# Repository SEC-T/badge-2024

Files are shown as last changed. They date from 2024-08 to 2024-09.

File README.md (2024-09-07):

# SEC-T 0x10sion Music Synthesizer Badge kit
photo of SEC-T 0x10sion Music Synthesizer Badge

The SEC-T 0x10sion Music Synthesizer Badge is a kit that attendees of SEC-T 0x10sion 2024 must solder together.
It is an Arduino-compatible music synthesizer kit with:
* a touch keyboard
* built-in speaker/amp
* audio output jack (for high-quality audio)
* 5 programmable RGB LEDs

It is designed to be perfect for total beginners to learn to solder and complete successfully.

The SEC-T Synth Badge comes with a pre-programmed music synthesizer that makes way cool sounds and music and noise.
Once soldering is completed, the SEC-T Synth Badge is a really nice, portable, performing musical instrument!

The SEC-T Synth Badge kit is based on the ArduTouch music synthesizer kit by Mitch Altman / Cornfield Electronics,
which is fully Open Hardware, with a CC BY-SA 4.0 license.

The SEC-T Synth Badge makes use of a modified ArduTouch library, which is available for
programming in more super nice synthesizer features, and for making your own synthesizers.
The library comes with examples (with more to come) that serve as a nice tutorial
on how to create your own SEC-T Synth Badge synthesizers (which are Arduino sketches).

The SEC-T Synth Badge is really just an Arduino Uno clone
with the features listed above, a couple of extra buttons, and a four of pots (for playing music and controlling the sounds).
The ArduTouch Arduino Library is where the real magic comes from!

For those who want to learn more, the documentation teaches the basics of Digital Signal Processing for audio generation.

The SEC-T Synth Badge kit is fully Open Hardware, with a CC BY-SA 4.0 license.

Open Hardware logo

---
## Assembly Instructions (with re-programming how-to)

_Click on the image below to open a PDF file with detailed instructions on how to assemble your SEC-T 0x10sion Music Synthesizer Badge (which also includes a how-to for re-programming your Synth Badge with a new Arduino sketch):_  
  
### Part 1 of 2 parts:
  
  
### Part 2 of 2 parts:
  

---
## "Quadrant" Synth Demo Videos

The Synth Badge comes pre-programmed with a synth called __Quadrant__.  
Quadrant is somewhat like a looper.  Every time you play a note it goes into the loop.  You can control the speed of the loop, and you can also make the sound warp (detune) every time through the loop.  
  
There is the default patch for Quadrant, plus 4 presets -- all 5 of these have very different sounds!  
In addition to changing the loop speed and changing the warp-factor, there are many parameters that you can play with, some of which change the sounds in subtle ways, others which change the sounds a lot.  

These demo videos give you a very small taste of the various sounds Quadrant can make. 

___NOTE__:  The demo videos use the prototype version of the SEC-T 0x10sion Music Synthesizer Badge kit._  
There are some differences between the prototype version and the badges at the event.  In particular, the two red buttons are reversed (left and right).  

__Basic Functionality of Quadrant__:  
* At power-up (or after Reset), Quadrant is in the Default Patch
* Single-Click the right red button to go up an octave
* Single-Click the left red button to go down an octave
* Double-Click the right red button and then hit one of the first four lower touch-keys to choose a preset
  * The left-most touch-key is "C" -- Scaffold
  * The next touch-key is "D" -- Farsy
  * "E" -- Teleprompt
  * "F" -- Glacial
  * "G" -- Blur
* Tap the Reset button to get the Default Patch
* The Top Pot controls the Warp-factor
* The Bottom Pot controls the speed of the loop
* Pot A controls tremelo speed
* Pot B controls tremelo depth
* Press-and-hold on the left and right red buttons will make the Red and Blue LEDs light or blink, indicating that the four Pots will now control different parameters.  
  
See the next section, "Quadrant Synth User Guide", for a complete description of all that the Quadrant Synth can do.  
  
### Default Patch (at power-up and after Reset) _-- click on the image below to play the video_
Thumb for Default Patch demo (https://www.youtube.com/watch?v=8XAPtq4mnFQ)  

### Preset "C" -- Scaffold _-- click on the image below to play the video_
Thumb for Preset "C" demo (https://www.youtube.com/watch?v=vg959F6WOIo)  

### Preset "D" -- Farsy _-- click on the image below to play the video_
Thumb for Preset "D" demo (https://www.youtube.com/watch?v=kQ33xrg7Zvw)  

### Preset "E" -- Teleprompt _-- click on the image below to play the video_
Thumb for Preset "E" demo (https://www.youtube.com/watch?v=aHm4yFb8vfQ)  

### Preset "F" -- Glacial _-- click on the image below to play the video_
Thumb for Preset "F" demo (https://www.youtube.com/watch?v=Ehx3G3c8V5c)  

### Preset "G" -- Blur _-- click on the image below to play the video_
Thumb for Preset "G" demo (https://www.youtube.com/watch?v=jeHlcZ8XYc8)  

---
## Quadrant Synth User Guide

The Synth Badge comes pre-programmed with a synth called __Quadrant__.  Quadrant is a very powerful performing musical instrument.  
_Click on the image below to learn how to play with it:_  
  

---
## Re-programming the Synth Badge

The Synth Badge can be re-programmed using the free Arduino software (on Windows, Linux, and MacOS).  
The end pages of the [Synth Assembly Instructions](https://github.com/user-attachments/files/16896082/SEC-T_0x10sion_badge_assembly_part_2of2.pdf) explain how to do this.  
To re-program your Synth Badge you will need to use a USB-Serial TTL adapter.  
  
The Synth Badge comes pre-programmed with the __Quadrant__ synth.  
  
There are 8 other synths that were developed for the open hardware_ArduTouch_ project (which the Synth Badge is based on), all of which will work on the SEC-T Synth Badge.  But you should be aware of the following:  
* The Synth Badge has 5 programmable RGB LEDs that the _ArduTouch_ boards do not have.  
* The __Quadrant__ synth sketch (from the Synth Badge's Github) has code for controlling the RGB LEDs, but the _ArduTouch synth sketches do not -- though this functionality can be added by you or others.  
* The Synth Badge does not have touch-keys for "A, A#, or B).
  
All of the documentation for [ArduTouch](https://cornfieldelectronics.com/cfe/projects.php#ardutouch), including the synth sketches, is available on the Cornfield Electronics website:  
https://cornfieldelectronics.com/cfe/projects.php#ardutouch  
  
Here is a list of ArduTouch synths that you can program into your Synth Badge:
* __Thick__: 4-voice sawtooth synth
* __Arpology__: Arpegiating synth
* __Beatitude__: drum sequencer with bass synth
* __Dronetic__: drone-making synth
* __Hocus__: Hammond organ (with Leslie) emulator synth
* __Mantra__: Indian-like percusion/bass/drone/melody synth
* __Xoid__: Digital-noise synth
* __ZapShot__: 8-bit video-game-sound synth

---
## A Note on the (Horrible) User Interface for the Quadrant Synth

As noted in the [Quadrant Synth User Guide](https://github.com/user-attachments/files/16901048/Quadrant_Synth_User_Guide.pdf) (see the "Quadrant Synth User Guide", above), the User Interface is really annoying.  

The following is quoted from the Quadrant Synth User Guide:  
  
&nbsp;&nbsp;&nbsp;&nbsp;&nbsp;&nbsp;_You will be annoyed at the User Interface for this synth.  Sorry about that.  The reason that it is so annoying  
&nbsp;&nbsp;&nbsp;&nbsp;&nbsp;&nbsp;is that there are so few Input/Output pins available on the microcontroller.  There were only enough I/O pins  
&nbsp;&nbsp;&nbsp;&nbsp;&nbsp;&nbsp;for 2 LED indicators, 2 Buttons, and 4 Pots._  
  
&nbsp;&nbsp;&nbsp;&nbsp;&nbsp;&nbsp;_I had to come up with a way to control all of the functionality of the Quadrant synth with only the above inputs  
&nbsp;&nbsp;&nbsp;&nbsp;&nbsp;&nbsp;and outputs.  The result is not ideal.  Yet, with some practice, you will find that your Quadrant synth is quite  
&nbsp;&nbsp;&nbsp;&nbsp;&nbsp;&nbsp;usable as a really nice performing musical instrument._  
  
&nbsp;&nbsp;&nbsp;&nbsp;&nbsp;&nbsp;_FYI:  I chose this microcontroller to be the same as the one used in an Arduino Uno:  ATmega328.  This was so  
&nbsp;&nbsp;&nbsp;&nbsp;&nbsp;&nbsp;that the project would be easy to use for beginners, easy to learn for beginners, easy to hack, and also as  
&nbsp;&nbsp;&nbsp;&nbsp;&nbsp;&nbsp;inexpensive as possible._  

---
## Schematic Diagram

_Click on the thumbnail below to to see the PDF file:_  


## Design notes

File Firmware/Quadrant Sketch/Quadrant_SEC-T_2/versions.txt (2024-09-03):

Versions:

   1.74sect added control for Neopixel LEDs, changed for 4 pots and only 9 touch-keys
   1.74c no need to explicitly clear flags.RSTMUTE
   1.74b add host/host.ini with pot labels
         add Stock.atp
   1.74a bck.bat copies host subdirectory and contents
         add host/preset .atp files for all presets
   1.73  use embedded U/I frames 
         syncs with library 1.16
   1.72  bugfix: upper bound condition in LED iteration corrected to "< NUMLEDs" from "<= NumLEDs"
         [31722] _STNDLONE_ lib 1.15 Build 1.6.6
   1.71  newOsc() returns NULL (instead of new Osc())
   1.70  nix BUILD_166 conditional compilation sections
   1.69  add FRAME21 pots to control lead 1 detune and transpose
         [31742] _STNDLONE_ BUILD_166
   1.68  edit presets/macros to use byte values <= 128 when setting LFO depths 
         syncs with library 1.13
         [31684] _STNDLONE_ BUILD_166
   1.67  === FIRST PUBLISHED VERSION ===

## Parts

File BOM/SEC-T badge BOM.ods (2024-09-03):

 | SEC-T Synth badges
Qty | Designator | Part Description | ordering url
1 | small bag | 5cm*7cm reclosable bags, 2 mil | https://www.amazon.se/-/en/plastic-closure-resealable-pressure-sealing/dp/B09QJYYYVR
4 | C1, C2, C3, C4 | 0.1uF, 50V, ceramic, 0.1" spacing leads | https://www.mouser.de/ProductDetail/80-C320C104K1R5TA
2 | C5, C6 | 100uF, 16V or higher, electrolytic, radial, 0.1" spacing leads | https://www.mouser.de/ProductDetail/710-860010473007
2 | C7, C8 | 1uF, 16V or higher, electrolytic, radial, 0.1" spacing leads | https://www.mouser.de/ProductDetail/232-450PK1MEFC6.3X11
1 | LED1 | Blue LED, 5mm | https://www.mouser.de/ProductDetail/710-151051BS04000
1 | LED2 | Red LED, 5mm | https://www.mouser.de/ProductDetail/442-BLBJE5V4VAT
1 | LED3 | Green LED, 5mm | https://www.mouser.de/ProductDetail/710-151051VS04000
1 | R1 | 10K, 1/4W, 5% | https://www.mouser.de/ProductDetail/708-CF18JT10K0
3 | R2, R3, R4 | 1K, 1/4W, 5% | https://www.mouser.de/ProductDetail/603-CFR-25JT-52-1K
2 | R5, R6 | 270, 1/4W, 5% | https://www.mouser.de/ProductDetail/603-CFR-25JT-52-270R
2 | R7, R8 | 4.7K, 1/4W, 5% | https://www.mouser.de/ProductDetail/603-CFR-25JR-524K7
1 | X1 | 16.0MHz ceramic resonator | https://www.mouser.de/ProductDetail/81-CSTLS16M0X53-B0
1 | medium bag | 12cm*8cm reclosable bags, 6.3 mil | https://www.amazon.se/-/en/huruirui-Resealable-Multiple-Assortment-Packaging/dp/B0BNC67X1M
1 | B1 | 3xAA battery holder w/ leads, switch, cover | https://www.mouser.de/ProductDetail/12BH331P-GR
1 | J1 | 1x6, right-angle (FTDI) | https://www.mouser.de/ProductDetail/649-1012937990604BLF
1 | J3 | headphone, stereo, 3.5mm, switched | https://www.mouser.de/ProductDetail/490-SJ1-3525NG-GR
1 | R9 | 10K trim pot (screwdriver adjust - Volume) | https://www.mouser.de/ProductDetail/652-3306F-1-103
4 | R10, R11, R12, R13 | 10K pot | https://www.mouser.de/ProductDetail/858-P120PKY25BR10K
1 | S1 | SPST tact switch, 4-pin, Black button (Reset) | https://www.mouser.de/ProductDetail/179-TS026660BK260LCR
2 | S2, S3 | SPST tact switch, 4-pin, Red button | https://www.mouser.de/ProductDetail/113-DTS65RV
1 | S4 | SPST slide switch | https://www.mouser.de/ProductDetail/611-OS102011MS2QS1
1 | U1 | ATmega328P-PU | https://www.mouser.de/ProductDetail/556-ATMEGA328P-PU
1 | U1 socket | 28-pin DIP socket | https://www.mouser.de/ProductDetail/571-1-2199298-9
1 | U2 | LM386N | https://www.mouser.de/ProductDetail/926-LM386N-1-NOPB
1 | U2 socket | 8-pin DIP socket | https://www.mouser.de/ProductDetail/571-1-2199298-2
1 | large bag | 15cm*20cm reclosable bags, 2 mil | https://www.amazon.se/-/en/gp/product/B0C9JKWSXJ
4 | LED4, LED5, LED6, LED7, LED8 | WS2812 RGB LED, 5mm | https://www.digikey.de/de/products/detail/sparkfun-electronics/COM-12986/5673799
1 | PCB | Multi-Circuit-Boards.eu | https://multi-circuit-boards.eu
1 | SPKR1 | speaker, 3W, 4 Ohm, 40mm diamater | https://www.electrokit.com/en/miniatyrhogtalare-8ohm-0.5w-20mm
1 | small bag (and its contents)
1 | med bag (and its contents)
1 | Card
1 | Lanyard | ~70cm long, with "J"-hook on each end

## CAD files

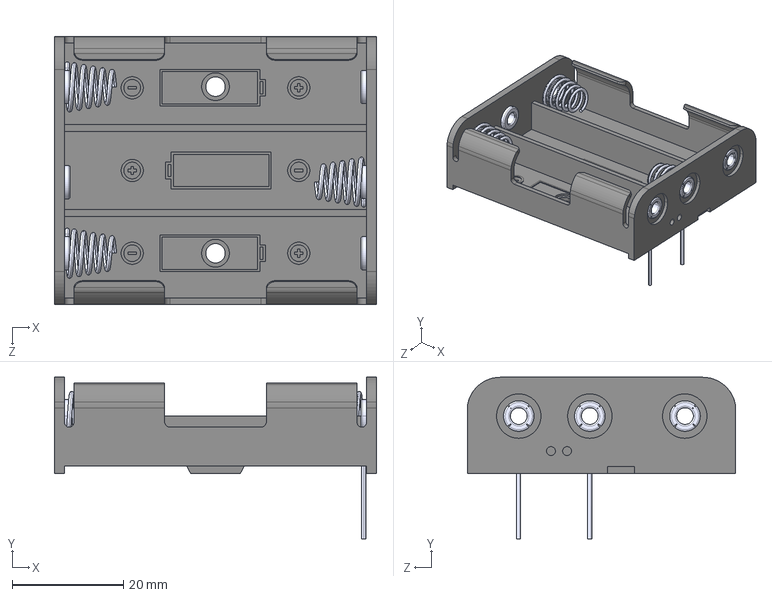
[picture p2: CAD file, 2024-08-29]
KiCad/3D_Models/12BH331P-GR--3DModel/12BH331P-GR--3DModel.STEP
58.0 x 29.1 x 48.3 mm

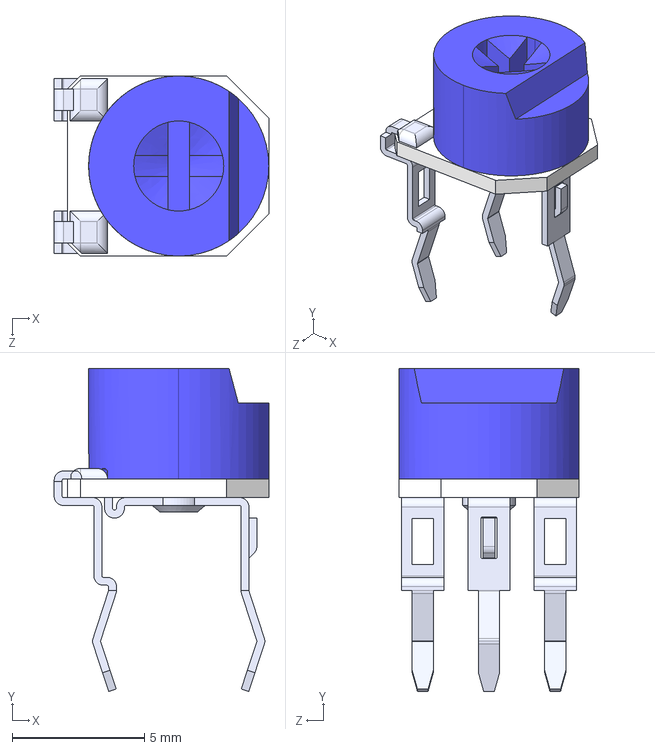
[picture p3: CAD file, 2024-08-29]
KiCad/3D_Models/3306F-1-103--3DModel/3306F-1-103.STEP
8.10 x 12.2 x 6.81 mm

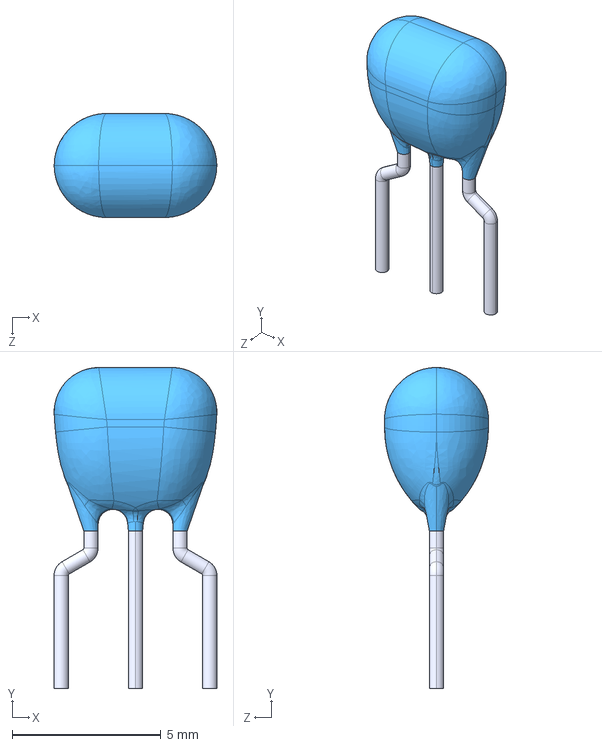
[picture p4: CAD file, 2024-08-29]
KiCad/3D_Models/CSTLS16M0X53-B0--3DModel/CSTLS16M0X53-B0.STEP
5.48 x 10.8 x 3.50 mm

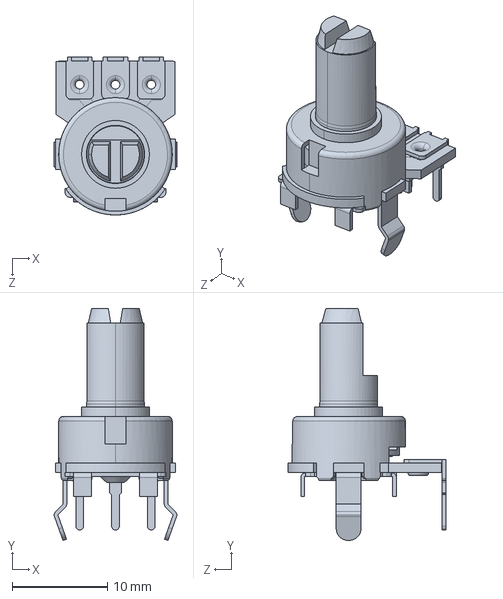
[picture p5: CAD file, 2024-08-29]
KiCad/3D_Models/P120PK-Y25BR10K--3DModel/P120PK-Y25BR10K.stp
12.8 x 24.3 x 16.6 mm

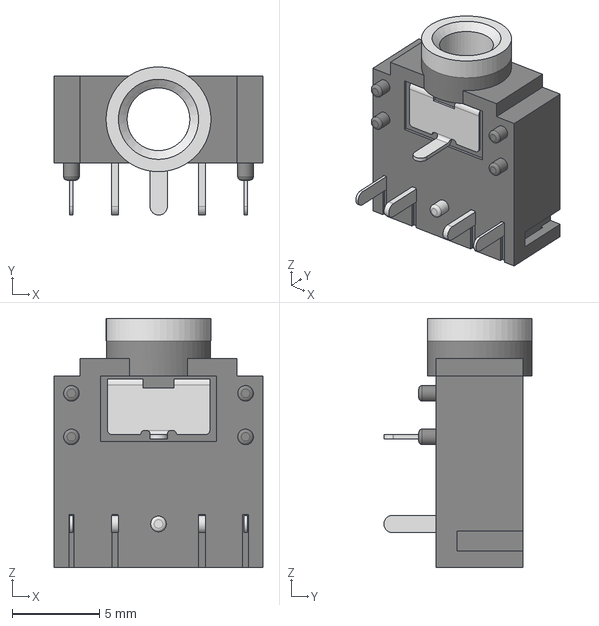
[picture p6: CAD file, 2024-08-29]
KiCad/3D_Models/SJ1-3525N--3DModel/SJ1-3525N.stp
12.0 x 8.51 x 14.3 mm

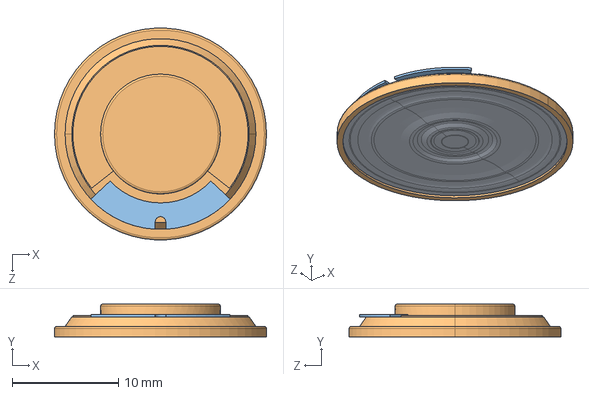
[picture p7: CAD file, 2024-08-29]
KiCad/3D_Models/speaker--3DModel/CUI_DEVICES_CDM-20008.step
20.0 x 3.10 x 20.0 mm

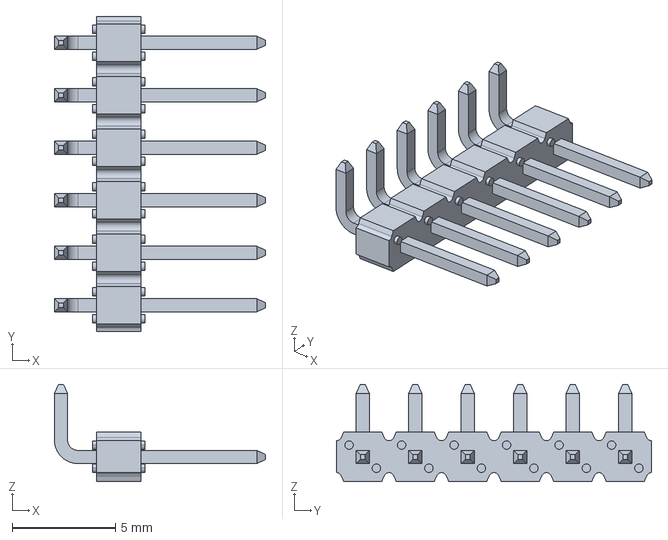
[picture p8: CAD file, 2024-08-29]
KiCad/3D_Models/10129379-906002BLF--3DModel/10129379-906002BLF--3DModel-STEP-533217.STEP
10.2 x 15.2 x 4.70 mm

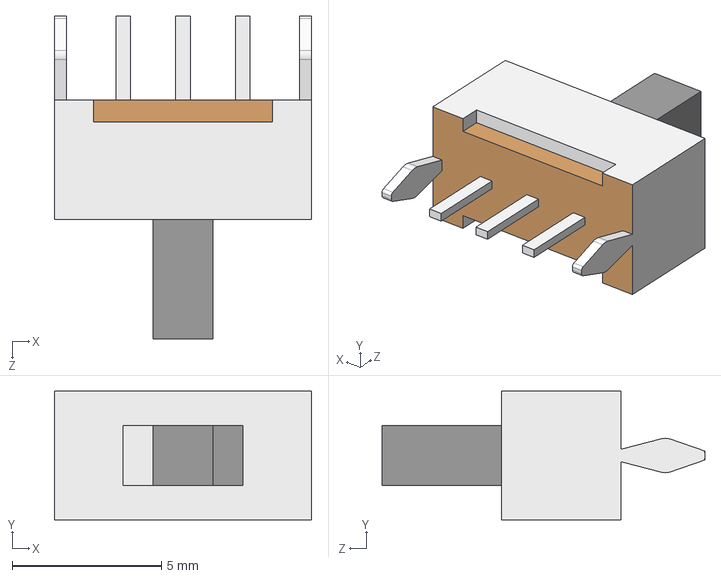
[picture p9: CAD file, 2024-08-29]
KiCad/3D_Models/OS102011MS2QS1--3DModel/OS102011MS2QS1.stp
8.60 x 4.30 x 10.8 mm

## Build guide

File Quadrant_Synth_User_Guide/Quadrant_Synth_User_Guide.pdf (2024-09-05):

## Quadrant

A partly echoing, partly arpeggiating, possibly warped synth for the ArduTouch / SEC‐T 0x10sion Music Synthesizer Bagde.

How to use:

-------- Presets --------

There are lots of way cool presets!

A list of all Presets can be seen on page 8 of this document.

Load preset sounds by Double-Tapping the Right Button and then pressing any bottom-row touch-key.

Note: A list of all types of Button presses this synth uses, including “Double-Tapping” can be seen on page 8 of this document.

Once you choose a preset, play notes on the keyboard and twiddle the knobs while playing and see what beautiful and also warped sounds and music you can create!

If you want to have more control over lots of cool and warped sounds available with the Quadrant synth, the following pages will explain how.

-------- A Note on the User Interface --------

You will be annoyed at the User Interface for this synth. Sorry about that. The reason that it is so annoying is that there are so few Input/Output pins available on the microcontroller. There were only enough I/O pins for 2 LED indicators, 2 Buttons, and 4 Pots.

I had to come up with a way to control all of the functionality of the Quadrant synth with only the above inputs and outputs. The result is not ideal. Yet, with some practice, you will find that your Quadrant synth is quite usable as a really nice performing musical instrument.

FYI: I chose this microcontroller to be the same as the one used in an Arduino Uno: ATmega328. This was so that the project would be easy to use for beginners, easy to learn for beginners, easy to hack, and also as inexpensive as possible.

==== Audio/Control Flow Diagram for the Quadrant Synth ====

| Tropes | --------.
v
.-----------> | | Echotron | |
| | v | v | v
| Lead 0 | ---> | | Mixer | | <--- | Lead 1 |
| v | v

[ Audio out ]

Lead 0 is duplicated in the opposite audio channel by Lead 1 (which may be transposed and/or detuned from Lead 0). The note information for Lead 0 is also fed into the Echotron. At the same time, a "trope" (an arpeggiation pattern) can be applied to the echoed note. The output from the Echotron is internally panned in stereo and then fed into a mixer along with the audio output from Lead 0 and Lead 1.

==== The Echotron Unit ====

The Echotron is a stereo synthesizer in its own right.

At the heart of the Echotron is a carousel of "slots", each of which holds an instance of an echoing note:

| | | | <--- WARP FACTOR
| | Note Carousel | |
| | | | <--- DELAY TIME
| Slot 0 < Slot 1 < Slot 2 < Slot 3 |
| | | | <--- FEEDBACK
v
note out

The carousel is constantly "revolving", outputting the note held in the current slot (the left-most slot in the above diagram), then shifting the slots.

The speed at which the carousel revolves is controlled by the DELAY TIME.

Each time a note echoes its volume will decrease by an amount controlled by the FEEDBACK setting. If FEEDBACK is set to its highest value (255) then the note will echo forever, or until all the slots in the carousel have been used up, and a new incoming note "overwrites" it.

Each time a note echoes its pitch can be raised or lowered by the current WARP FACTOR.

The number of slots in the carousel is configurable and can be set interactively via the Parameter Menu (see below) to between 1 and 4.

----- Tropes ------

The above description of the note carousel is a simplification. In fact, each slot can contain not just a note, but also a pointer to a "trope" (an arpeggiation pattern) in ROM. Each time the carousel revolves it will play the next note in the arpeggiation pattern for that slot.

----- Note HOLD ------

You can instruct the Echotron to HOLD the next note played (see the Parameter Menu below). When a note is on HOLD it will not decrease in volume as it echoes, and it will not be overwritten by incoming notes when the carousel is full. This is a very useful feature for setting up a constant bass pulse and jamming over it. Better yet, if a trope is active when you hold the note, then you can set up a whole bass line or texture to be played over. And you can hold more than one note :)

----- SAMPLE & HOLD ------

You can globally freeze whatever sound loop the Echotron is producing by enabling SAMPLE & HOLD (toggled via the Parameter Menu, see below). Then you can jam over it freely.

----- ISO-TEMPO -------

This feature allows the Echotron to maintain a constant tempo, regardless of the number of notes in the carousel. So if there are 4 notes currently echoing in the carousel and ISO-TEMPO is on, then the delay time will be 1/4 of what it would be if there were only 1 note in the carousel. The "Telepromt" and "Frara Jaqua" presets use ISO-TEMPO. You can toggle ISO_TEMPO via the Parameter Menu (see below). (NOTE: The "Frara Jaqua" preset is not available on the Synth Badge.)

----- ENVELOPE ------

A master envelope dynamically controls the amplitude of the notes produced by the Echotron. This envelope is a traditional ADSR (Attack/Decay/Sustain/Release) but with a twist: a Sustain Time parameter is added. When the envelope for an echoing note reaches the sustain stage it will automatically release after the
amount of time specified by the sustain time parameter. The various stages of the master envelope can be controlled via the Pots (see below).

----- PULSE WIDTH ------

The notes produced by the Echotron use square wave oscillators. The PULSE WIDTH of these oscillators can be modified via a Pot (see below). The pulse width controls the ratio between the positive and negative edges of the square wave and can radically alter the timbre of the tones.

----- AUTO-WAH ------

The Echotron has a pair of internal autowahs (oscillating low-pass filters) which are applied to the note output before it is panned. Three parameters control the autowah behaviour: CUTOFF frequency, oscillation FREQ, and oscillation DEPTH. All of these can be modified via the Pots (see below).

----- PAN CONTROL ------

A PAN control dynamically rotates the note output in the stereo field. The DEPTH and FREQ of the panning can be controlled via the Pots (see below).

==== Overview Diagram of the Echotron ====

Now that we have covered each component, here is an overall view:

[HOLD] | notes | in | [SAMPLE & HOLD]
\ | |
\ | v
----------------- | < WARP >
Trope in ---> | | Note Carousel | | < DELAY > | [ISO-TEMPO]
----------------- | < FEEDBACK >
------------- | | | < # SLOTS >
| ENVELOPE | | notes | out
| <Attack> | | |
| <Decay> | | | v
| <Sustain> | | -----------------------------
| <SusTime> | | | | AutoWahs | |
| <Release> | | | <CUTOFF> <FREQ> <DEPTH> |
v | v
-----------------------------| <---- Pan Control ----> |
| | <FREQ> <DEPTH> | |
| | audio out | |
v | v

==== PLAYING THE KEYBOARD ====

The Quadrant keyboard is a mono-touch instrument: you can play one note at a time.

To raise the keyboard by an octave, Tap the Right Button once.
To lower the keyboard by an octave, Tap the Left Button once.

==== USING THE POTS TO CONTROL PARAMETERS ====

The four Pots can be used to control 18 different parameters. You can choose four parameters to control with the Left and Right Buttons.

By Pressing (not Tapping) the Left and Right Buttons you can change which four parameters the Pots control. Each time a Button is Pressed, its associated LED (Red LED for Left Button, Blue LED for Right Button) will change state (from OFF to ON to BLINKING, back to OFF etc.)

Below is a chart showing which four parameters the Pots control when the LEDs are in a given state:

Red Blue LED LED | Top POT Bottom POT Adjust A POT Adjust B POT
OFF OFF | echo echo autowah autowah WARP DELAY time FREQ DEPTH
ON OFF | echo lead/echo autowah echo FEEDBACK BALANCE CUTOFF PULSE WIDTH
BLINK OFF | panning panning lead 1 lead 1 FREQ DEPTH DETUNE** TRANSPOSE***
OFF ON | autowah autowah envelope envelope FREQ DEPTH ATTACK* DECAY*
ON ON | autowah echo envelope envelope CUTOFF PULSE WIDTH SUSTAIN* RELEASE*
BLINK ON | lead 1 lead 1 echo lead DETUNE** TRANSPOSE*** SUSTIME PORTAMENTO
OFF BLINK | envelope envelope DECAY* ----ATTACK*
ON BLINK | envelope envelope RELEASE* ----SUSTAIN*
BLINK BLINK | echo lead PORTAMENTO (weirdness) --SUSTIME

* these Pots can be configured via the Parameter Menu (see next section) to control:
1) only the LEAD voices
2) only the ECHO voices
3) both the LEAD and ECHO voices

** detunes lead1 from lead 0

*** transposes lead1 from lead0 (range is from -2 to +2 octaves)

==== USING THE PARAMETER MENU ====

You can control additional parameters by using the Parameter Menu.

To access the Parameter Menu Double-Tap the Left Button. The LEDs will now start blinking on and off in alternation: this tells you that the Parameter Menu is active. When the Parameter Menu is active the keys will no longer play notes but each key will select and modify a particular parameter as described below. Depending on the parameter, the Pot positions may also be relevant, as described below. The Parameter Menu is active until you press a key on the touch-keyboard: then the parameter associated with that key is modified, and the Parameter Menu is automatically exited (restoring the prior user interface state).

You can exit the Parameter Menu without modifying any parameters by Double-Tapping the Left Button a second time.

The list below describes what actions are taken when a key is pressed:

Key | Action
C | toggle Sample-and-Hold on/off
C# | turn Sample-and-Hold off, and unhold all held notes
D | hold next note played
D# | [ reserved ]
E | toggle lead voices on/off
F | set # of slots in carousel based on Top Pot position *
F# | toggle isoTempo or/off
G | select trope based on Bottom Pot position **
G# | [ reserved ]
A | ADSR Pots control envelopes of both lead and echo voices ***
A# | ADSR Pots control envelopes of lead voices only ***
B | ADSR Pots control envelopes of echo voices only ***

* turn Top Pot 0 to desired position (all the way left = 1,
all the way right = 4) then press F

** turn Bottom Pot to desired position (all the way left = "no trope" ) then press G

*** A, A#, and B are not available on the SEC-T Synth Badge

==== GUIDE TO QUADRANT’S PRESETS ====

The default patch is active when powered on, and after Tapping the Reset Button.

Load presets by Double-Tapping the Right Button and then pressing any bottom-row touch-key.

The presets are as follows:

Key Name | Performance Notes
C | Scaffold | lead voices off (and should stay off)
D | Farsy
E | Teleprompt lead voices off (turn them on once 2 slots are playing)
F | Glacial | play very slowly
G | Blur
A | ToneJack | *
B | FraraJaqua lead voices off (turn them on once 4 slots are playing) *

* ToneJack and FraraJaqua are not available on the SEC-T Synth Badge

Types of Button presses:

Tap: | quickly tap a Button
Press: | long‐press a Button
Double‐Tap: quickly double‐tap a Button

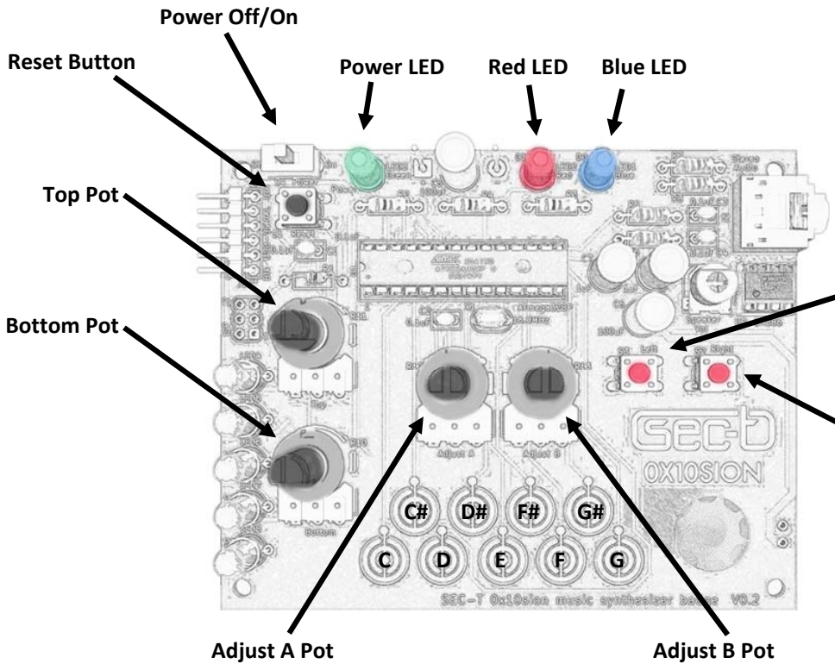
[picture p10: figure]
Power Off/On; Reset Button; Power LED; Red LED; Blue LED; Bottom Pot; Top Pot; Adjust A Pot; Adjust B Pot

Left Button

Right Button

----------------------------------------------------------------------About Quadrant's Tuning

When you start playing notes on the keyboard you will probably notice that the 'C' key plays an 'F'. And if you have a really good ear you may also notice that the interval between C# and G# is not exactly a 5th.

Why is this?

To explain the 2nd observation first, Quadrant uses Harmonic Tuning (also known as Just Temperament or "Helmholtz's scale") instead of the usual Equal Temperament (which is the system default).

Harmonic Tuning is actually more "natural" than Equal Temperament (which was created as a compromise so that keyboard instruments could play in all keys). In Harmonic Tuning the relative frequencies of all notes compared to the tonic ('C' in our case) are rational numbers:

Unison | 1/1
Minor Second 25/24
Major Second | 9/8
Minor Third | 6/5
Major Third | 5/4
Fourth | 4/3
Diminish 5th 45/32
Fifth | 3/2
Minor Sixth | 8/5
Major Sixth | 5/3
Minor Seventh 9/5
Major Seventh 15/8
Octave | 2/1

The Echotron uses quantum square wave oscillators which can only be set to frequencies which have integral wavelengths. The frequencies produced by these oscillators conform more closely to a scale in Harmonic Tuning than one in Equal Temperament.

But why does the 'C' key play an 'F'?

The short answer is that on the ArduTouch, whose audio rate is ~15.6 kHz, 'F' (in octave 1) has a period of 360 samples. 360 is a number favored by the ancients because it is divisible by a large number of integers: 1, 2, 3, 4, 5, 6, 8, 9, 10, 12, 15, 18, 20, 24, etc. It so happens that by using a tonic frequency whose period is 360, we are able to use quantum oscillators to closely approximate the Harmonic Tuning scale over several octaves. Low 'F', so to speak, is the natural tonic frequency of the ArduTouch.*

Since Quadrant's tuning is only an approximation to an 'F' Harmonic tuning, certain musical scales (such as E Major, F# Major on the ArduTouch keyboard) will sound a bit sour. C Major / D Minor work best.

* Actually, on the ArduTouch a waveform with a period of 360 samples generates a tone with a frequency of 43.578 Hz. In the equal temperament scale, 'F' in octave 1 has a frequency of 43.654 Hz.

Copyright (C) 2024, Mitch Altman
Copyright (C) 2020, Cornfield Electronics, Inc.

This work is licensed under the Creative Commons Attribution-ShareAlike 4.0
Unported License.

To view a copy of this license, visit http://creativecommons.org/licenses/by-sa/4.0/

Created by Bill Alessi & Mitch Altman.

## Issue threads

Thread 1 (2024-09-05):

Synth Badge Assembly Instructions (and re-programming guide) -- Part 1 of 2 parts

maltman23, 2024-09-05:
[SEC-T_0x10sion_badge_assembly_part_1of2_front_page.pdf](https://github.com/user-attachments/files/16895987/SEC-T_0x10sion_badge_assembly_part_1of2_front_page.pdf)

maltman23, 2024-09-05:
fixed title

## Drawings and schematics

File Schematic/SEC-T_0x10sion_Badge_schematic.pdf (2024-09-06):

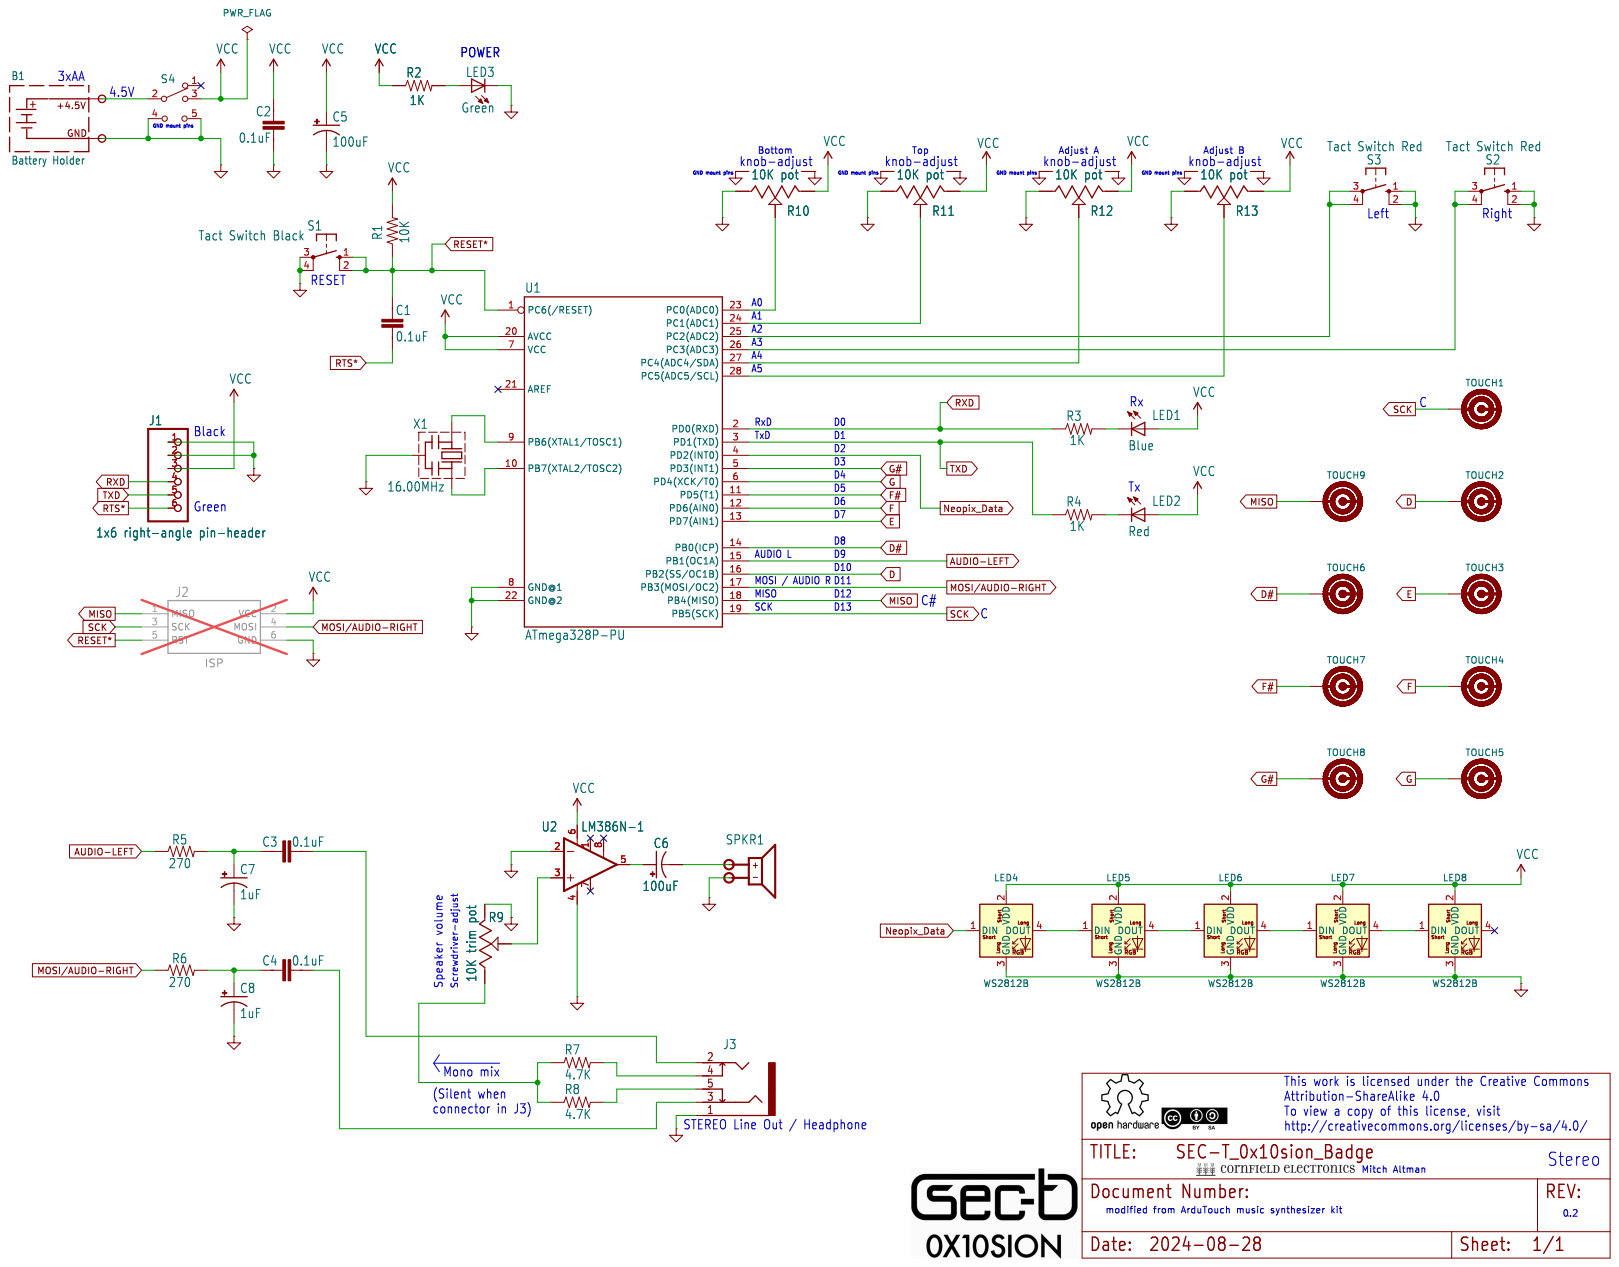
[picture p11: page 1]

AUDIO-LEFT MOSI/AUDIO-RIGHT SCK MISO

AUDIO-LEFT MOSI/AUDIO-RIGHT

This work is licensed under the Creative Commons
To view a copy of this license, visit

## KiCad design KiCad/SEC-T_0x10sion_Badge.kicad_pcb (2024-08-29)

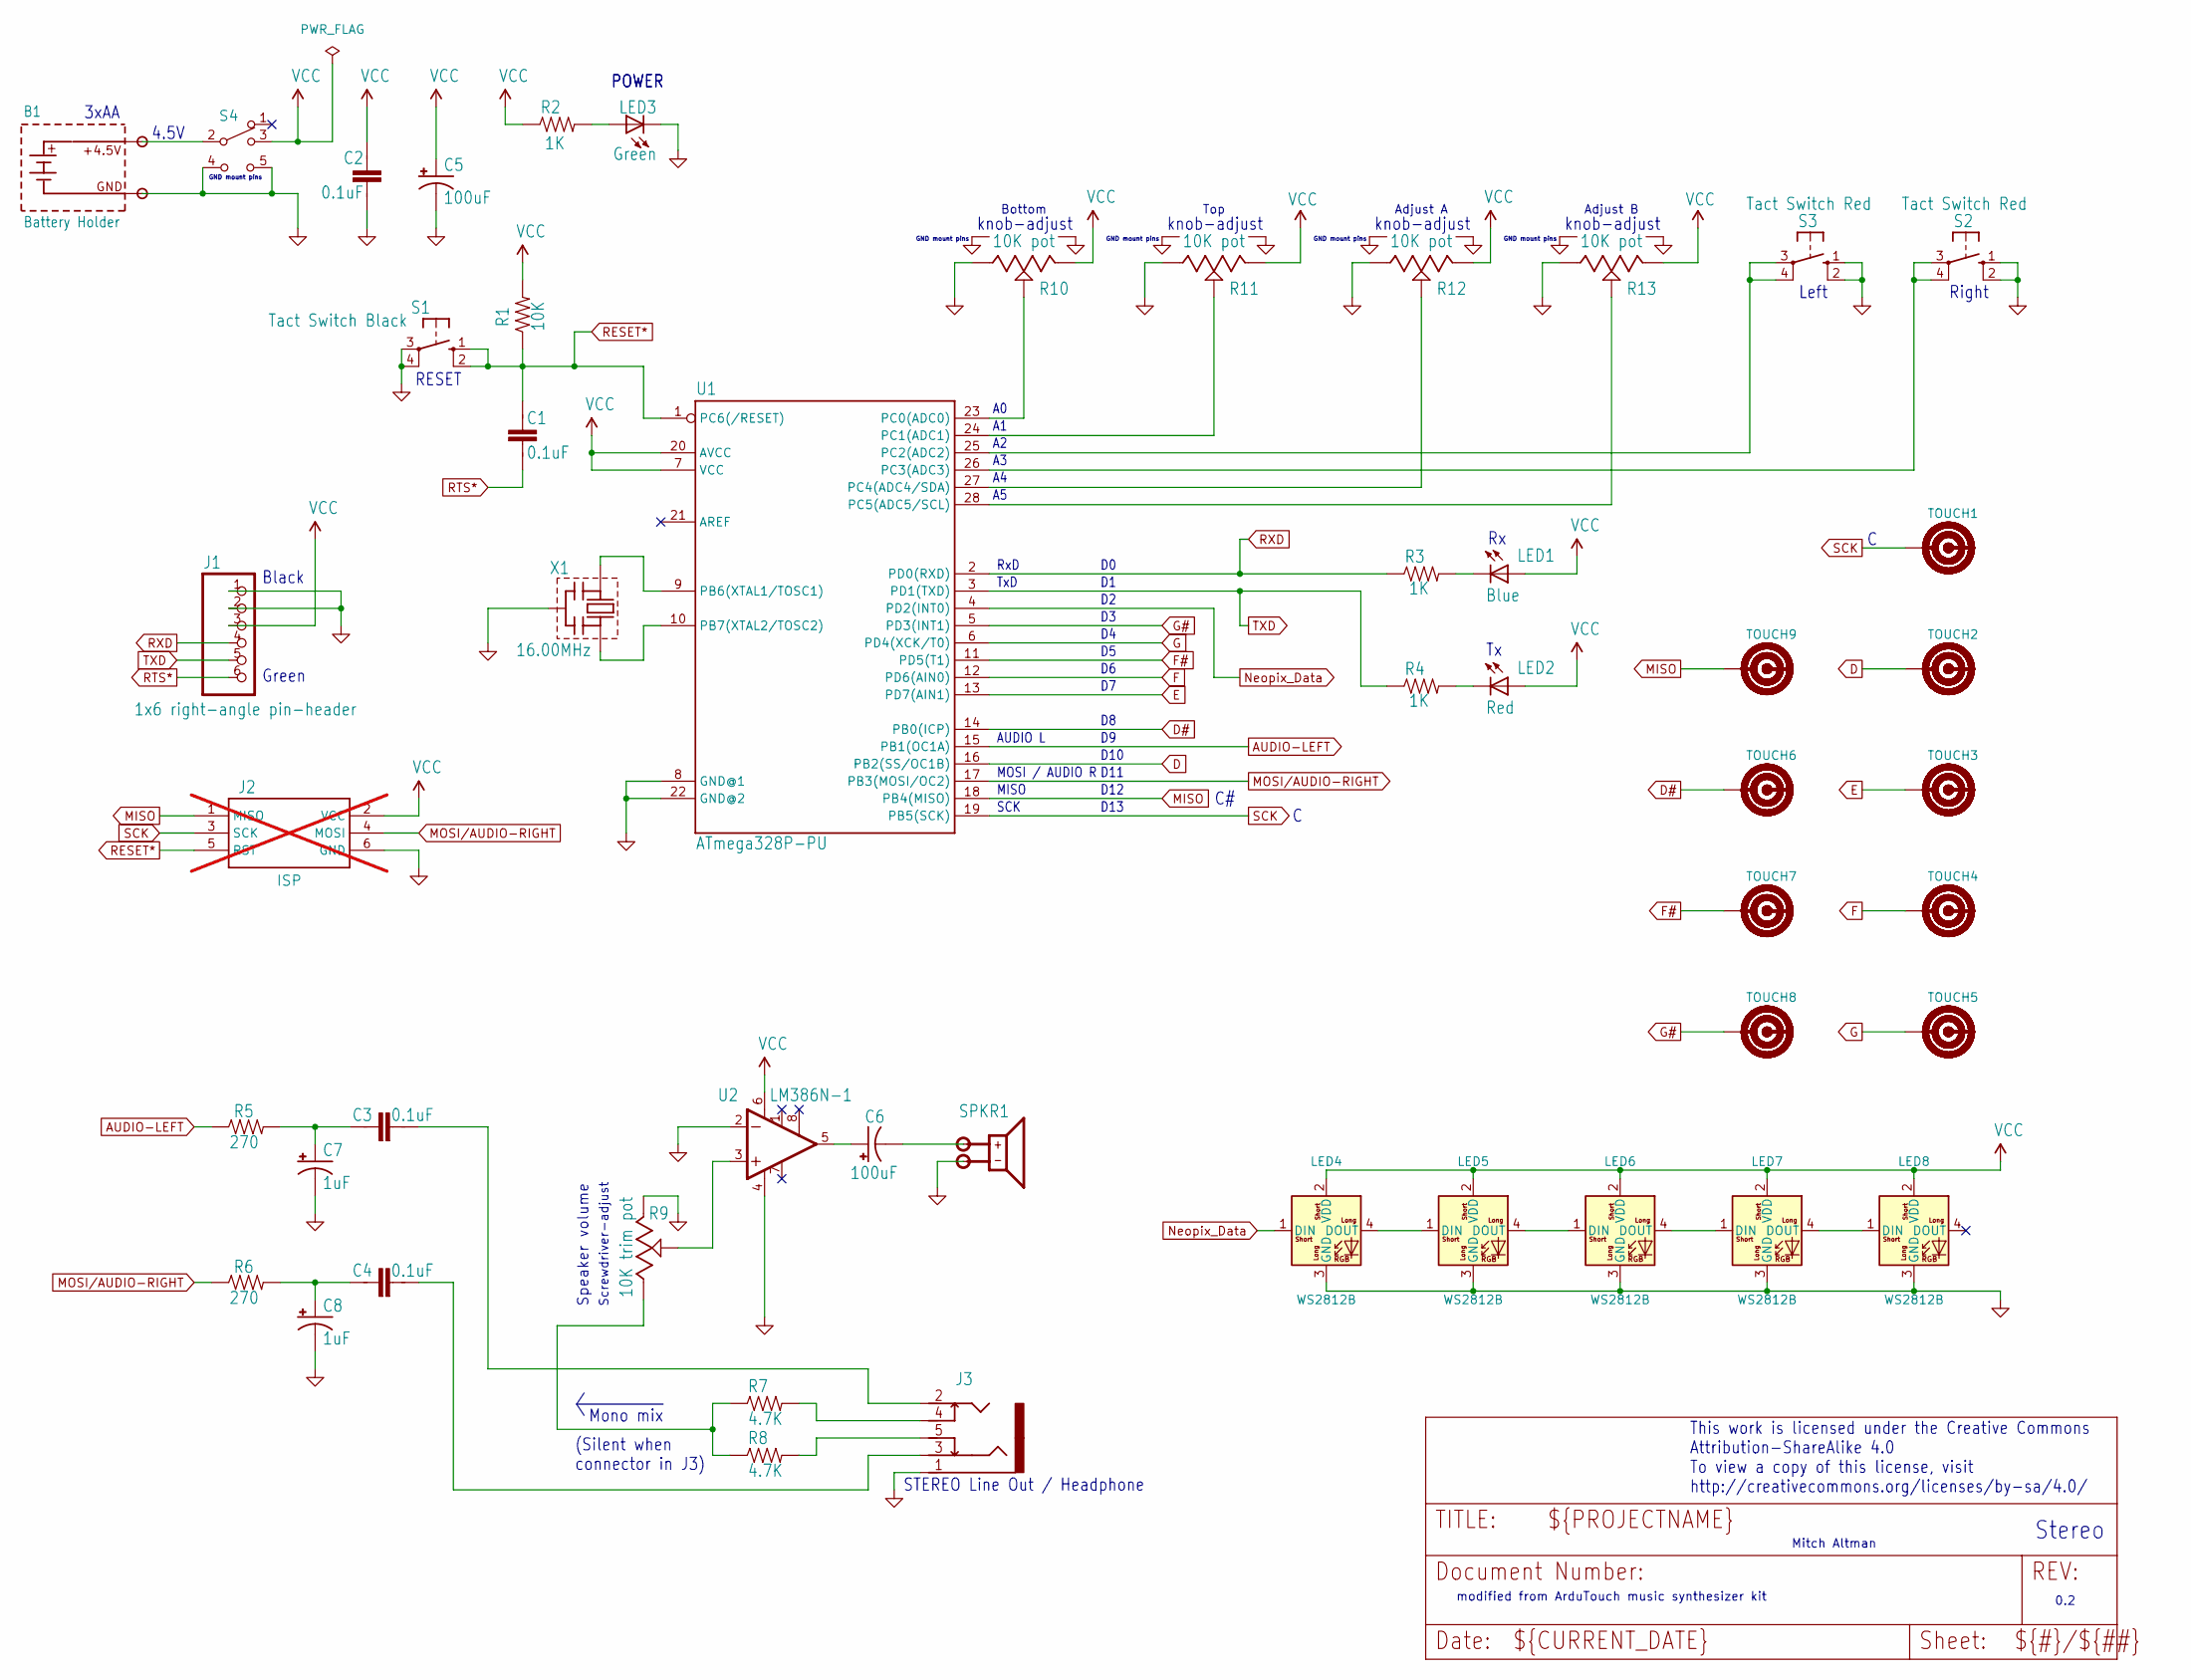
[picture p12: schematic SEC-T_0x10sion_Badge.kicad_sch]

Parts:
B1: Battery Holder; BatteryHolder_Eagle_Plastic_Devices_3xAA; Part # Eagle Plastic 12BH331P-GR
C1, C2, C3, C4: 0.1uF; Cap_Kemet_2.54_MLCC_through-hole; Part # KEMET C320C104M5R5TA
C5, C6: 100uF; Cap_Wurth_Electrolytic_100uF; Part # Wurth 860010473007
C7, C8: 1uF; Cap_Rubycon_Electrolytic_1uF; Part # Rubycon 450PK1MEFC6.3X11
J1: 1x6 right-angle pin-header; 1x06-pin-header_2.54mm_spacing; Part # Amphenol 10129379-906004BLF
J2: ISP; 2x3_-pin-header_2.54mm_spacing; Part # {not stuffed); not fitted
J3: STEREO-AUDIO-3.5MM-SWITCHED; 3.5mm_CUI_SJ1-3525NG_Horizontal; Part # CIU Devices SJ1-3525NG-GR
LED1: Blue; LED5MM; Part # Wurth 151051BS04000
LED2: Red; LED5MM; Part # Wurth 151051SS04000
LED3: Green; LED5MM; Part # Wurth 151051VS04000
LED4, LED5, LED6, LED7, LED8: WS2812B; LED_WS2812_5mm_Wide_Pins; Part # SparkFun COM-12986
R1: 10K; Resistor_THT_0.25W; Part # SEI Stackpole CF18JT10K0
R2, R3, R4: 1K; Resistor_THT_0.25W; Part # YAGEO CFR-25JR-52-1K
R5, R6: 270; Resistor_THT_0.25W; Part # YAGEO CFR25SJT-26-270R
R7, R8: 4.7K; Resistor_THT_0.25W; Part # YAGEO CFR25SJT-52A4K7
R9: 10K trim pot; TRIMPOT-Bourns-3306F
R10, R11, R12, R13: 10K pot; Potentiometer_TT_P120PK; Part # TT Electronics P120PK-Y25BR10K
S1: Tact Switch Black; TACTILE_SWITCH_6.3MM; Part # CUI Devices TS02-66-60-BK-260-LCR-D
S2, S3: Tact Switch Red; TACTILE_SWITCH_6.3MM; Part # Diptronics DTS-65R-V
S4: SPST; C&K_SPST_OS102011MS2QS1; Part # C&K OS102011MS2QS1
SPKR1: SPEAKER-TERMINALS; Part # DONGGUAN INGHAI ELECTRONICS GSPK2003TN-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
TOUCH1, TOUCH2, TOUCH3, TOUCH4, TOUCH5, TOUCH6, TOUCH7, TOUCH8, TOUCH9: PCB-TOUCHPAD
U1: ATmega328P-PU; DIP-28_W7.62mm_Socket
U2: LM386N-1; DIP-8_W7.62mm; Part # Texas Instruments LM386N-1/NOPB
X1: 16.00MHz; CERM_OSC_16MHz; Part # Murata CSTLS16M0X53-B0

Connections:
AUDIO-LEFT: R5.P$1 (1), U1.15 (PB1(OC1A))
D: TOUCH2.1, U1.16 (PB2(SS/OC1B))
D#: TOUCH6.1, U1.14 (PB0(ICP))
E: TOUCH3.1, U1.13 (PD7(AIN1))
F: TOUCH4.1, U1.12 (PD6(AIN0))
F#: TOUCH7.1, U1.11 (PD5(T1))
G: TOUCH5.1, U1.6 (PD4(XCK/T0))
G#: TOUCH8.1, U1.5 (PD3(INT1))
GND: B1.-, C2.2, C5.-, C7.-, C8.-, J1.1, J1.2, J2.6 (GND), J3.1 (GND), LED3.K (C), LED4.3 (GND), LED5.3 (GND), LED6.3 (GND), LED7.3 (GND), LED8.3 (GND), R9.1 (CCW), R10.1 (CCW), R10.GND, R11.1 (CCW), R11.GND, R12.1 (CCW), R12.GND, R13.1 (CCW), R13.GND, S1.3, S1.4, S2.1, S2.2, S3.1, S3.2, S4.4 (GND), S4.5 (GND), SPKR1.-, U1.8 (GND@1), U1.22 (GND@2), U2.2 (-IN), U2.4 (V-), X1.P$2 (GND)
MISO: J2.1 (MISO), TOUCH9.1, U1.18 (PB4(MISO))
MOSI/AUDIO-RIGHT: J2.4 (MOSI), R6.P$1 (1), U1.17 (PB3(MOSI/OC2))
Neopix_Data: LED4.1 (DIN), U1.4 (PD2(INT0))
unnamed: B1.+, S4.2
unnamed: C6.-, SPKR1.+
unnamed: C4.2, J3.3 (Ring)
unnamed: J3.5 (Ring_Switch), R8.P$2 (2)
unnamed: C3.2, J3.2 (Tip)
unnamed: J3.4 (Tip_Switch), R7.P$2 (2)
unnamed: LED1.K (C), R3.P$2 (2)
unnamed: LED2.K (C), R4.P$2 (2)
unnamed: LED4.4 (DOUT), LED5.1 (DIN)
unnamed: LED5.4 (DOUT), LED6.1 (DIN)
unnamed: LED6.4 (DOUT), LED7.1 (DIN)
unnamed: LED7.4 (DOUT), LED8.1 (DIN)
unnamed: LED3.A, R2.P$2 (2)
unnamed: C3.1, C7.+, R5.P$2 (2)
unnamed: C4.1, C8.+, R6.P$2 (2)
unnamed: R7.P$1 (1), R8.P$1 (1), R9.3 (CW)
unnamed: R9.2 (Wiper), U2.3 (+IN)
unnamed: R10.2 (Wiper), U1.23 (PC0(ADC0))
unnamed: R11.2 (Wiper), U1.24 (PC1(ADC1))
unnamed: R12.2 (Wiper), U1.27 (PC4(ADC4/SDA))
unnamed: R13.2 (Wiper), U1.28 (PC5(ADC5/SCL))
unnamed: U1.9 (PB6(XTAL1/TOSC1)), X1.P$1 (IN)
unnamed: U1.10 (PB7(XTAL2/TOSC2)), X1.P$3 (OUT)
unnamed: S3.3, S3.4, U1.25 (PC2(ADC2))
unnamed: S2.3, S2.4, U1.26 (PC3(ADC3))
unnamed: C6.+, U2.5 (OUT)
RESET*: C1.1, J2.5 (RST), R1.P$1 (1), S1.1, S1.2, U1.1 (PC6(/RESET))
RTS*: C1.2, J1.6
RXD: J1.4, R3.P$1 (1), U1.2 (PD0(RXD))
SCK: J2.3 (SCK), TOUCH1.1, U1.19 (PB5(SCK))
TXD: J1.5, R4.P$1 (1), U1.3 (PD1(TXD))
VCC: C2.1, C5.+, J1.3, J2.2 (VCC), LED1.A, LED2.A, LED4.2 (VDD), LED5.2 (VDD), LED6.2 (VDD), LED7.2 (VDD), LED8.2 (VDD), R1.P$2 (2), R2.P$1 (1), R10.3 (CW), R11.3 (CW), R12.3 (CW), R13.3 (CW), S4.3, U1.7 (VCC), U1.20 (AVCC), U2.6 (V+)

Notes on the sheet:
GND mount pins
Top
Bottom
RESET
Screwdriver-adjust
knob-adjust
RxD
This work is licensed under the Creative Commons Attribution-ShareAlike 4.0 To view a copy of this license, visit http://creativecommons.org/licenses/by-sa/4.0/
4.5V
D10
D13
Adjust A
D11
Mono mix
modified from ArduTouch music synthesizer kit
Adjust B
Black
MOSI / AUDIO R
POWER
3xAA
MISO
Green
AUDIO L
Right
D12
0.2
Stereo
STEREO Line Out / Headphone
TxD
Left
Speaker volume
(Silent when connector in J3)
Mitch Altman
SCK

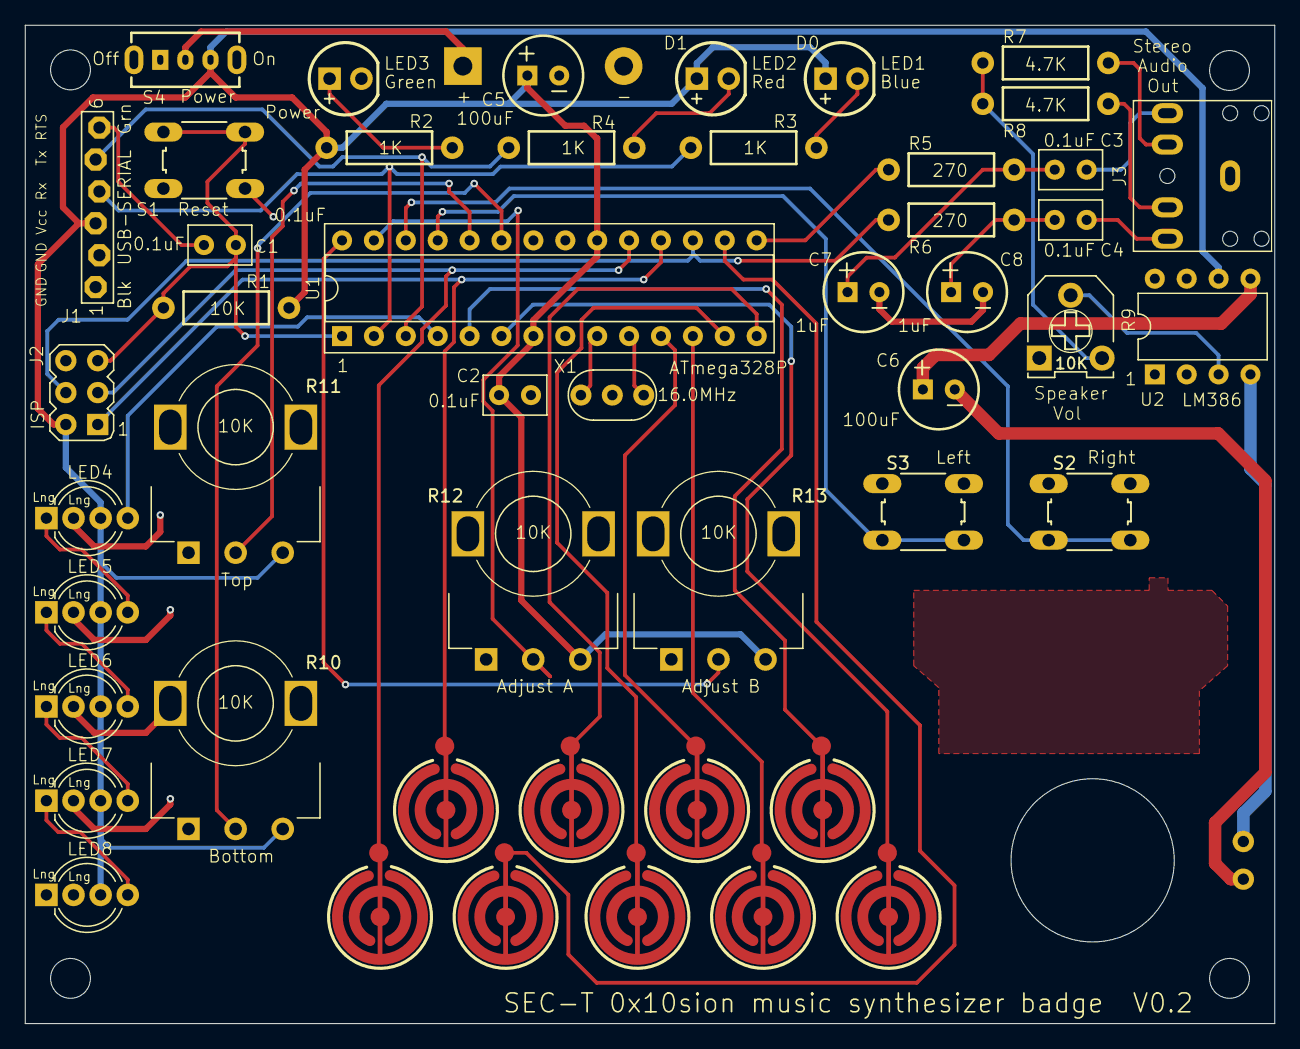
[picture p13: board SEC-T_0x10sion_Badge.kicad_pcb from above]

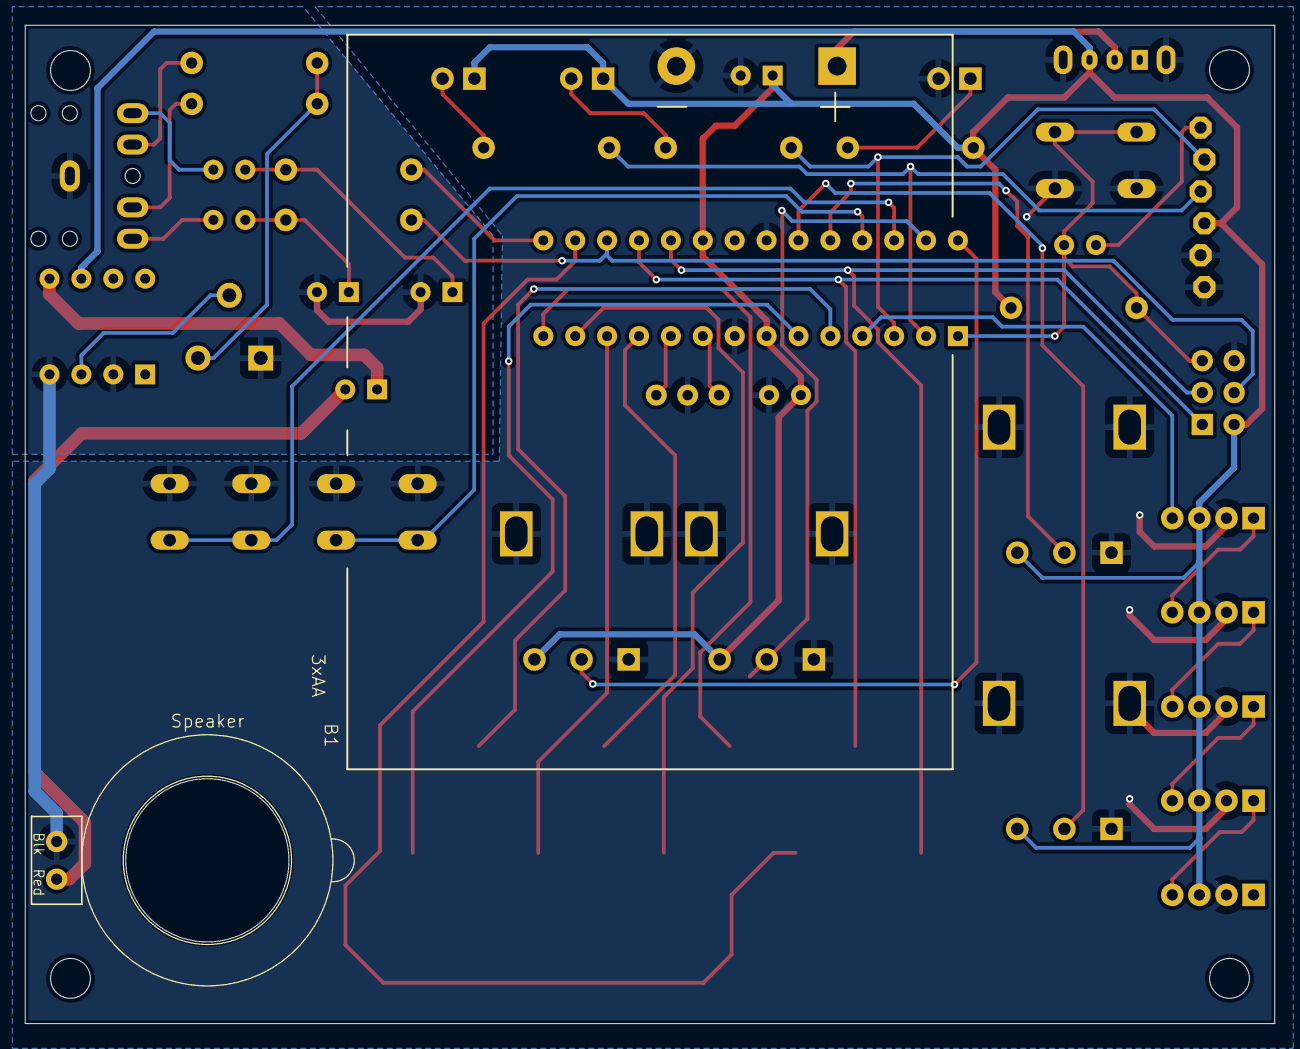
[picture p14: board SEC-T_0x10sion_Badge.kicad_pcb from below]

Board: 2 copper layers, 99.5 x 79.5 mm, 54 parts (2 on the bottom side), 44 nets.

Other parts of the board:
@HOLE0, @HOLE1, @HOLE2, @HOLE3: (no value)

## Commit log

2024-08-29 Add README, License, KiCad files
    Add first draft of README.md, License.md, and the production version of all KiCad source files (SEC-T_0x10sion_Badge v0.2).
    [10129379-906002BLF--3DModel-STEP-533217.STEP, 12BH331P-GR--3DModel.STEP, 3306F-1-103.STEP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]
2024-09-03 BOM, Arduino library, Quadrant sketch
    Add BOM, ArduTouch Arduino library, Quadrant sketch
    [SEC-T badge BOM.ods]
2024-09-04 Create SEC-T_0x10sion_badge_assembly.pdf
    Add Assembly Instructions / Re-programming how-to
2024-09-05 Update README.md
    Added Assembly instructions (with re-programming how-to)
2024-09-05 Update comments in Quadrant sketch, add Quadrant User Guide
    * Update comments in Quadrant sketch to fix a couple of errors and add some info on ArduTouch vs SEC-T Synth Badge.
    * Add Quadrant User Guide.
    [Quadrant_SEC-T_2.ino]
2024-09-06 add schematic
2024-09-07 Update README.md
    Added schematic diagram
2025-09-12 Update SEC-T_0x10sion_badge_assembly.pdf
    Update Assembly Instructions to use Kester K100LD Rosin solder.
2026-09-11 updated assembly instructions
    Updated assembly instructions to include new good lead-free solder choices
